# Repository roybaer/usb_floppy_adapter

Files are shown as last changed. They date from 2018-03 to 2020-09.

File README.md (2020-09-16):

# USB to Floppy-Disk Drive Adapter

This project provides the CAD files for an STM32-based floppy-disk controller that can be attached to the back of an ordinary 3.5 inch floppy-disk drive and connected to a USB host via micro USB port.

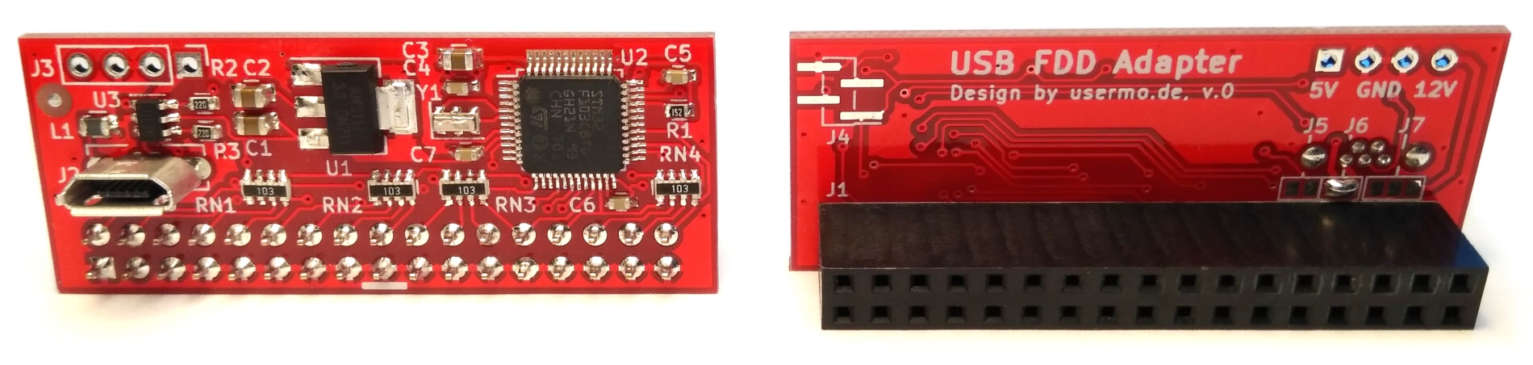
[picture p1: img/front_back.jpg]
USB FDD Adapter front and back


## Hardware

The core of this adapter is the popular STM32F103C8T6 microcontroller by STMicroelectronics.
Please consult the [PDF schematic](schematic.pdf) for details.

### Configuration

The adapter can be used in several different hardware configurations that can be selected via solder bridges.

The following drive types are supported:

- PC drives
- IBM PS/2 drives
- drives with shugart interface

Drives that only use the 5V line and consume less than approx. 480mA can be powered via USB, other drives have to be powered externally.

J5    | J6    | J7       | Use case
------|-------|----------|---------
▒▒░▒▒ | ▒▒░▒▒ | ▒▒░▒▒░▒▒ | PC drive, externally powered
▓▓▓▓▓ | ▒▒░▒▒ | ▒▒░▒▒░▒▒ | IBM PS/2 drive without 12V line
▒▒░▒▒ | ▓▓▓▓▓ | ▒▒░▒▒░▒▒ | PC drive, USB-powered
▒▒░▒▒ | ▒▒░▒▒ | ▓▓▓▓▓░▒▒ | pin 4 and 6 shorted, for shugart drives that do not use pin 4
▒▒░▒▒ | ▒▒░▒▒ | ▒▒░▓▓▓▓▓ | 12V on pin 4, for PS/2 drive

The power connector J3 can be used as either input or output.

Configurations other than the USB-powered PC drive (see [picture](img/pc_drive.jpg)) are untested.

## Firmware

As of August 2020, there is no working firmware for this adapter, yet.

The objective is to adapt the firmware provided by the [Greaseweazle project](https://github.com/keirf/Greaseweazle).
It does already provide support for the same microcontroller, albeit for a much bulkier adapter with a different pinout.

### Programming via Serial Wire Debug Interface

The adapter provides solder pads for an SWD programming device. They are labeled J4 on the PCB.

Pin on J4 | Function
----------|---------
1 | 3.3V
2 | SWDIO
3 | SWCLK
4 | GND

## Software

Please refer to the Greaseweazle documentation for PC-side software that will be used with this adapter.

## License

The following license applies to the files in this repository:

This work is licensed under the Creative Commons Attribution-ShareAlike 4.0 International License. To view a copy of this license, visit http://creativecommons.org/licenses/by-sa/4.0/ or send a letter to Creative Commons, PO Box 1866, Mountain View, CA 94042, USA.

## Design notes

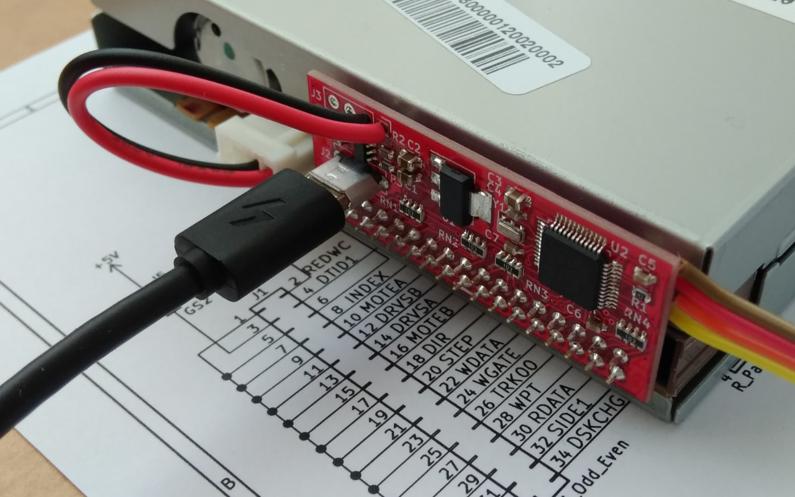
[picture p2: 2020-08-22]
img/pc_drive.jpg

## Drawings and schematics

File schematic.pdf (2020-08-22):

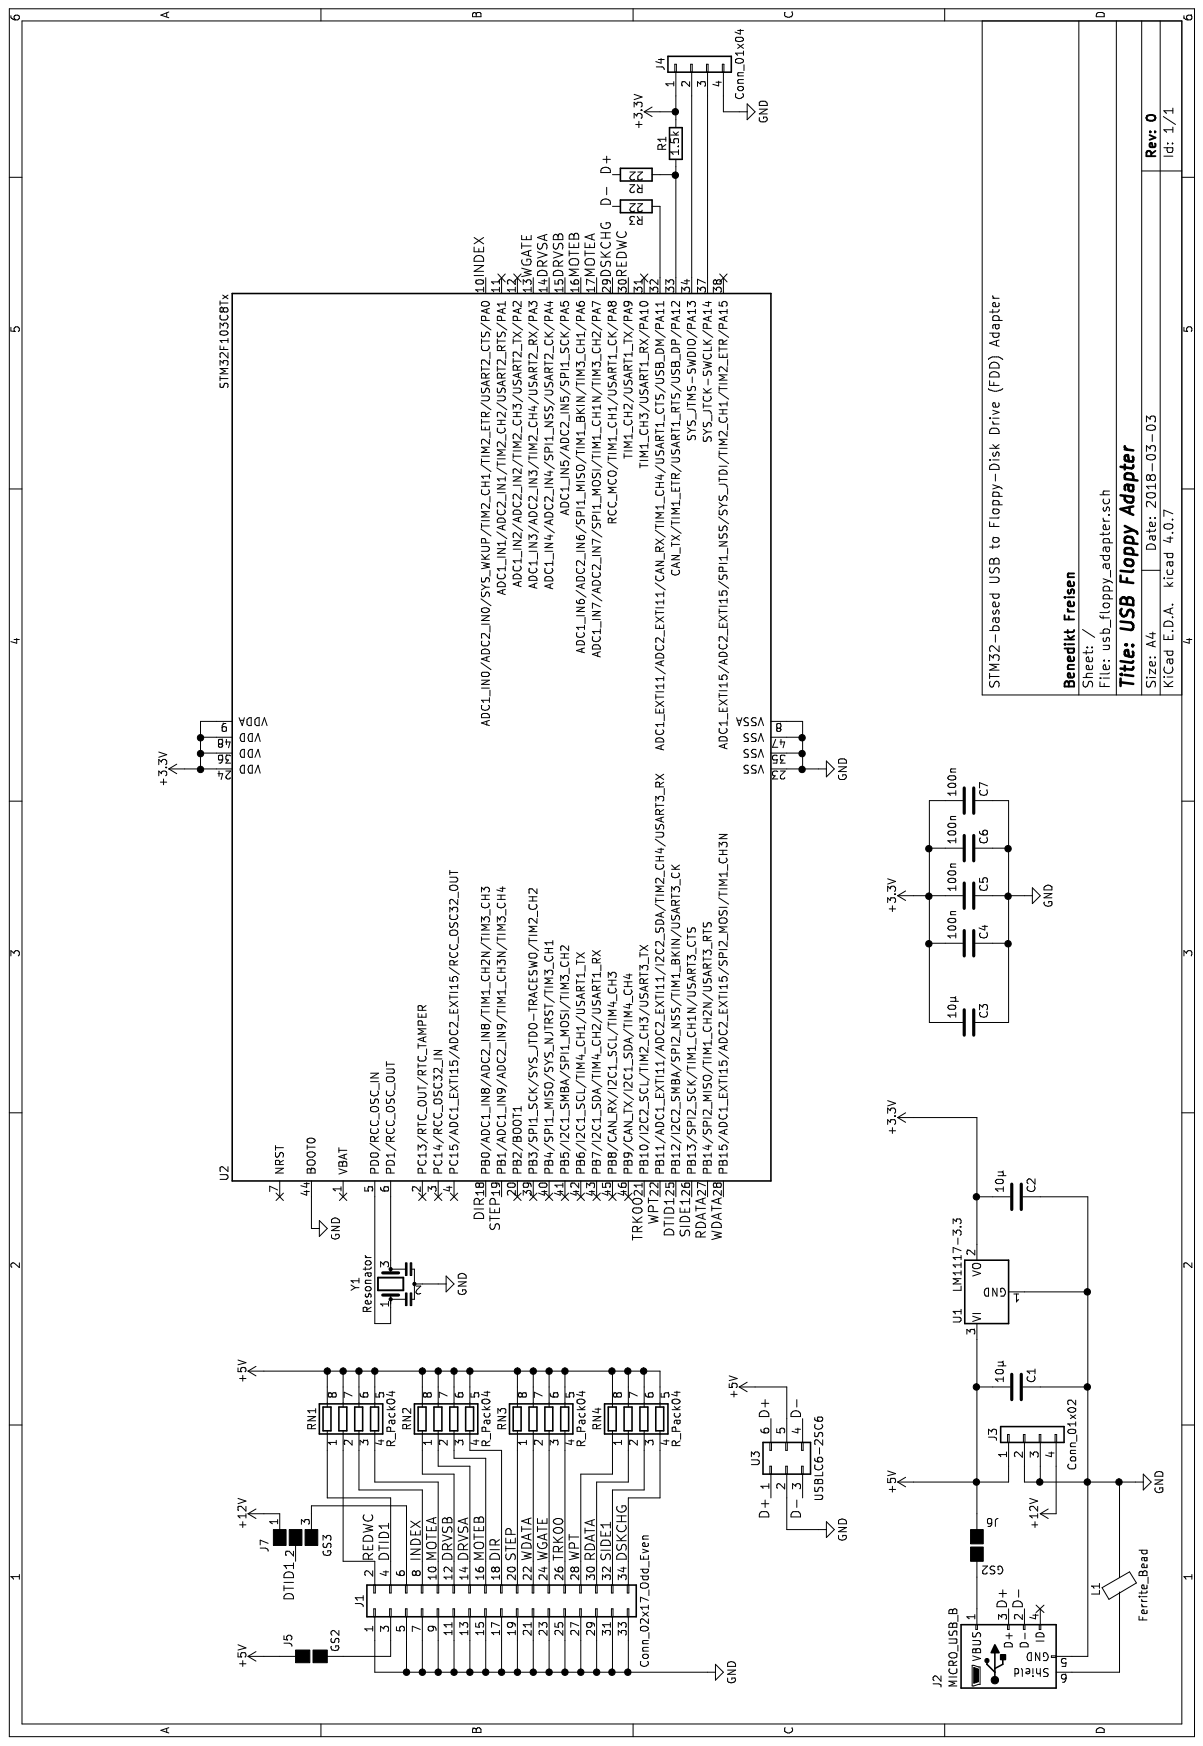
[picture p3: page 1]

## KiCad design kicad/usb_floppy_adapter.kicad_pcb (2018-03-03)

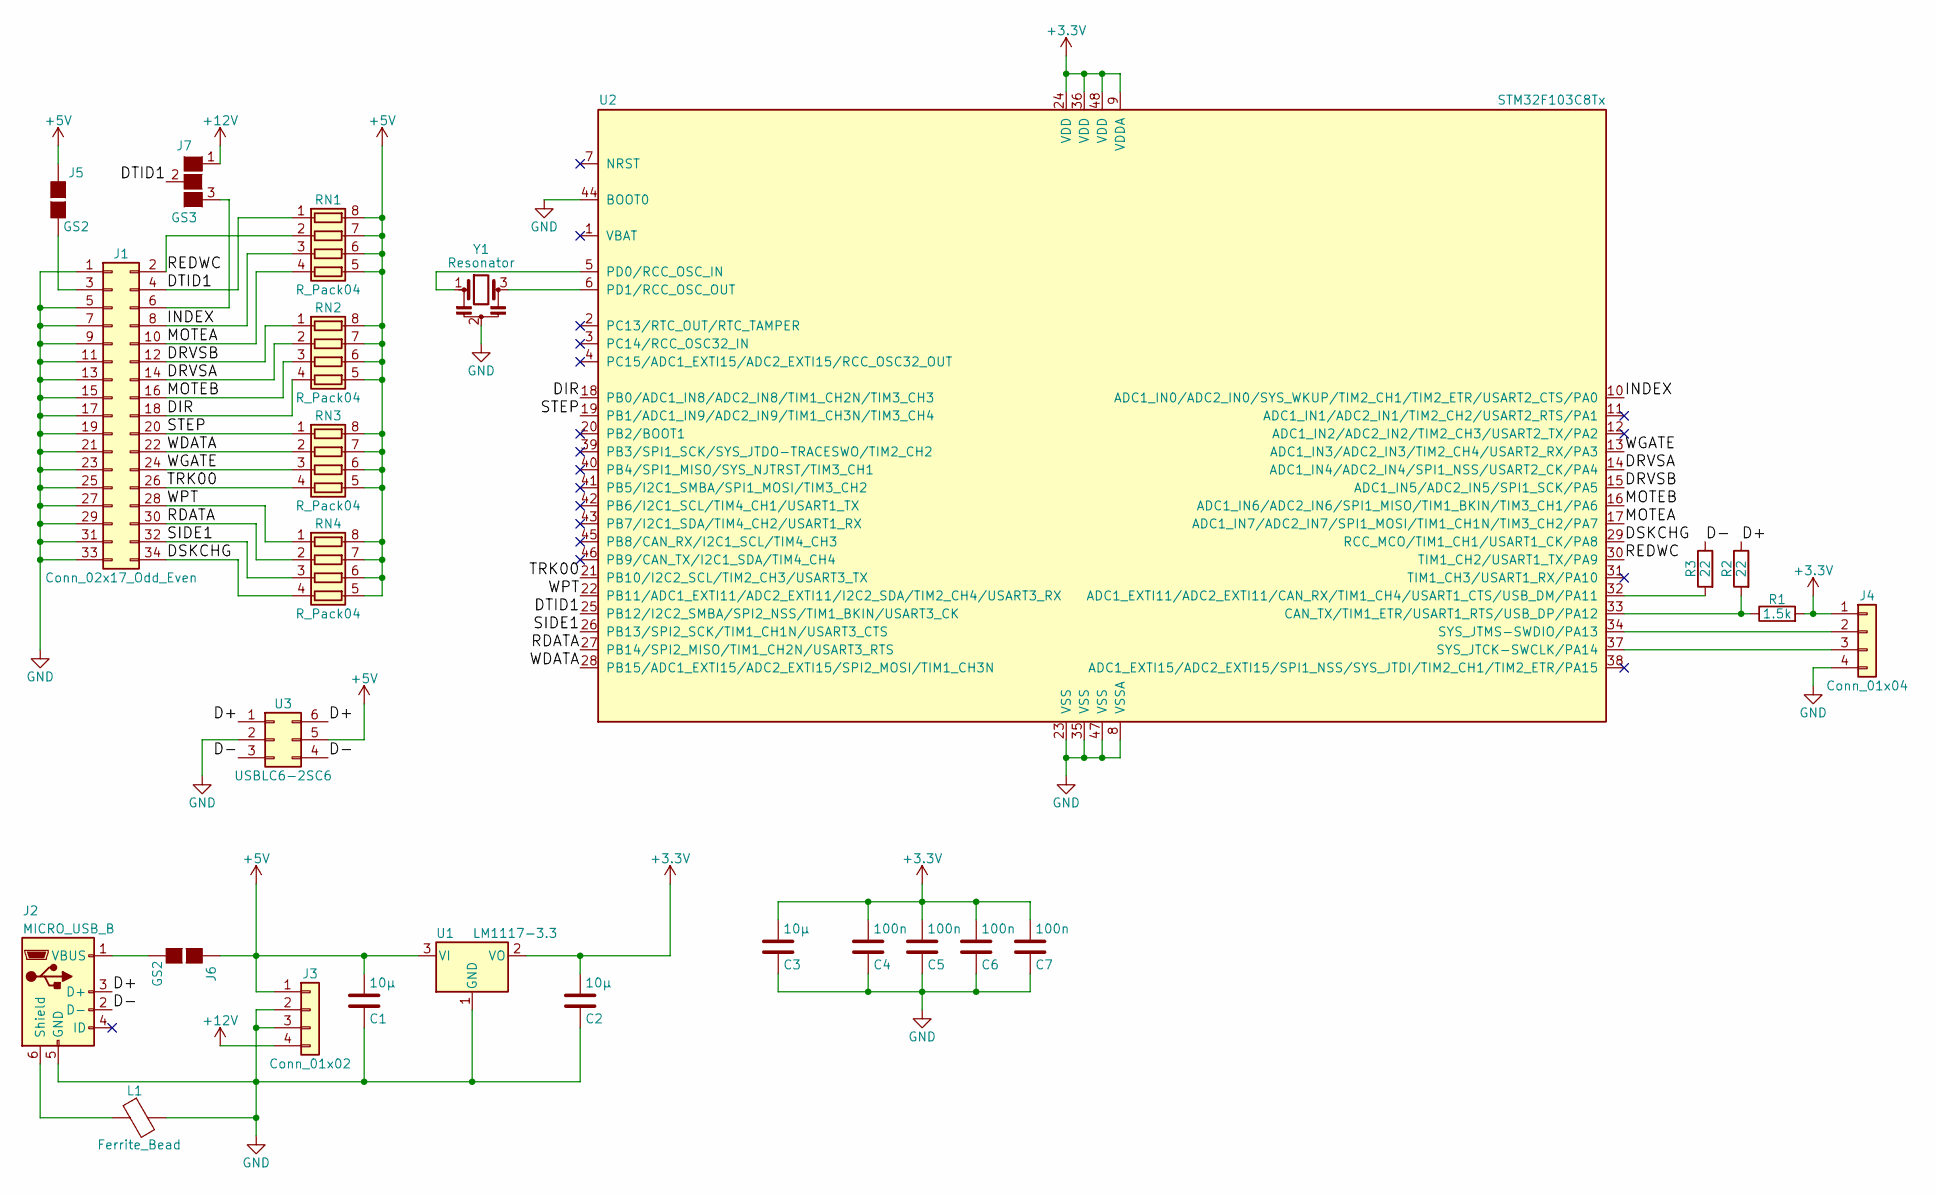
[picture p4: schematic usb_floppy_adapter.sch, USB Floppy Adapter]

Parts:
C1, C2, C3: 10µ; C_0805
C4, C5, C6, C7: 100n; C_0603
J1: Conn_02x17_Odd_Even; Socket_Strip_Straight_2x17_Pitch2.54mm
J2: MICRO_USB_B; USB_Micro-B_Vertical_Molex-105133-0001
J3: Conn_01x02; Pin_Header_Straight_1x04_Pitch2.54mm
J4: Conn_01x04; Pin_Header_Straight_1x04_Pitch1.27mm_SMD_Pin1Left
J5, J6: GS2
J7: GS3
L1: Ferrite_Bead; L_0805
R1: 1.5k; R_0603
R2, R3: 22; R_0603
RN1, RN2, RN3, RN4: R_Pack04; R_Array_Convex_4x0603
U1: LM1117-3.3; SOT-223-3Lead_TabPin2
U2: STM32F103C8Tx; LQFP-48_7x7mm_Pitch0.5mm
U3: USBLC6-2SC6; SOT-23-6
Y1: Resonator; Resonator_SMD_muRata_SFECV-3pin_6.9x2.9mm

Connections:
+3V3: C2.2, C3.2, C4.2, C5.2, C6.2, C7.2, J4.1, R1.2, U1.2 (VO), U2.9 (VDDA), U2.24 (VDD), U2.36 (VDD), U2.48 (VDD)
+5V: C1.2, J3.1, J5.1 (G1), J6.1 (G1), RN1.5 (R4.2), RN1.6 (R3.2), RN1.7 (R2.2), RN1.8 (R1.2), RN2.5 (R4.2), RN2.6 (R3.2), RN2.7 (R2.2), RN2.8 (R1.2), RN3.5 (R4.2), RN3.6 (R3.2), RN3.7 (R2.2), RN3.8 (R1.2), RN4.5 (R4.2), RN4.6 (R3.2), RN4.7 (R2.2), RN4.8 (R1.2), U1.3 (VI), U3.5
+12V: J3.4, J7.1 (G1)
/D+: J2.3 (D+), R2.1, U3.1, U3.6
/D-: J2.2 (D-), R3.1, U3.3, U3.4
/DIR: J1.18, RN2.4 (R4.1), U2.18 (PB0/ADC1_IN8/ADC2_IN8/TIM1_CH2N/TIM3_CH3)
/DRVSA: J1.14, RN2.2 (R2.1), U2.14 (ADC1_IN4/ADC2_IN4/SPI1_NSS/USART2_CK/PA4)
/DRVSB: J1.12, RN2.1 (R1.1), U2.15 (ADC1_IN5/ADC2_IN5/SPI1_SCK/PA5)
/DSKCHG: J1.34, RN4.4 (R4.1), U2.29 (RCC_MCO/TIM1_CH1/USART1_CK/PA8)
/DTID1: J1.4, J7.2 (G2), RN1.1 (R1.1), U2.25 (PB12/I2C2_SMBA/SPI2_NSS/TIM1_BKIN/USART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)
/INDEX: J1.8, RN1.3 (R3.1), U2.10 (ADC1_IN0/ADC2_IN0/SYS_WKUP/TIM2_CH1/TIM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)
/MOTEA: J1.10, RN1.4 (R4.1), U2.17 (ADC1_IN7/ADC2_IN7/SPI1_MOSI/TIM1_CH1N/T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)
/MOTEB: J1.16, RN2.3 (R3.1), U2.16 (ADC1_IN6/ADC2_IN6/SPI1_MISO/TIM1_BKIN/T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)
/RDATA: J1.30, RN4.2 (R2.1), U2.27 (PB14/SPI2_MISO/TIM1_CH2N/USART3_RTS)
/REDWC: J1.2, RN1.2 (R2.1), U2.30 (TIM1_CH2/USART1_TX/PA9)
/SIDE1: J1.32, RN4.3 (R3.1), U2.26 (PB13/SPI2_SCK/TIM1_CH1N/USART3_CTS)
/STEP: J1.20, RN3.1 (R1.1), U2.19 (PB1/ADC1_IN9/ADC2_IN9/TIM1_CH3N/TIM3_CH4)
/TRK00: J1.26, RN3.4 (R4.1), U2.21 (PB10/I2C2_SCL/TIM2_CH3/USART3_TX)
/WDATA: J1.22, RN3.2 (R2.1), U2.28 (PB15/ADC1_EXTI15/ADC2_EXTI15/SPI2_MOSI/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)
/WGATE: J1.24, RN3.3 (R3.1), U2.13 (ADC1_IN3/ADC2_IN3/TIM2_CH4/USART2_RX/PA3)
/WPT: J1.28, RN4.1 (R1.1), U2.22 (PB11/ADC1_EXTI11/ADC2_EXTI11/I2C2_SDA/T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)
GND: C1.1, C2.1, C3.1, C4.1, C5.1, C6.1, C7.1, J1.1, J1.5, J1.7, J1.9, J1.11, J1.13, J1.15, J1.17, J1.19, J1.21, J1.23, J1.25, J1.27, J1.29, J1.31, J1.33, J2.5 (GND), J3.2, J3.3, J4.4, L1.2, U1.1 (GND), U2.8 (VSSA), U2.23 (VSS), U2.35 (VSS), U2.44 (BOOT0), U2.47 (VSS), U3.2, Y1.2
unnamed: J1.3, J5.2 (G2)
unnamed: J1.6, J7.3 (G3)
unnamed: J2.1 (VBUS), J6.2 (G2)
unnamed: J2.6 (Shield), L1.1
unnamed: J4.2, U2.34 (SYS_JTMS-SWDIO/PA13)
unnamed: J4.3, U2.37 (SYS_JTCK-SWCLK/PA14)
unnamed: R1.1, R2.2, U2.33 (CAN_TX/TIM1_ETR/USART1_RTS/USB_DP/PA12)
unnamed: R3.2, U2.32 (ADC1_EXTI11/ADC2_EXTI11/CAN_RX/TIM1_CH4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)
unnamed: U2.5 (PD0/RCC_OSC_IN), Y1.1
unnamed: U2.6 (PD1/RCC_OSC_OUT), Y1.3

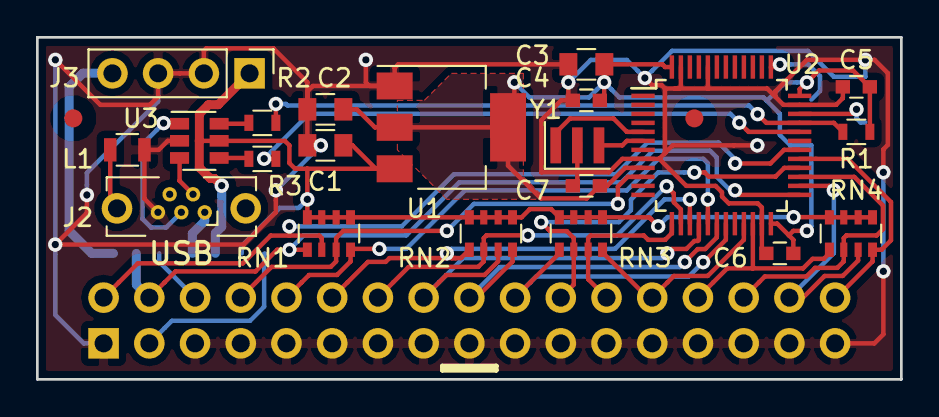
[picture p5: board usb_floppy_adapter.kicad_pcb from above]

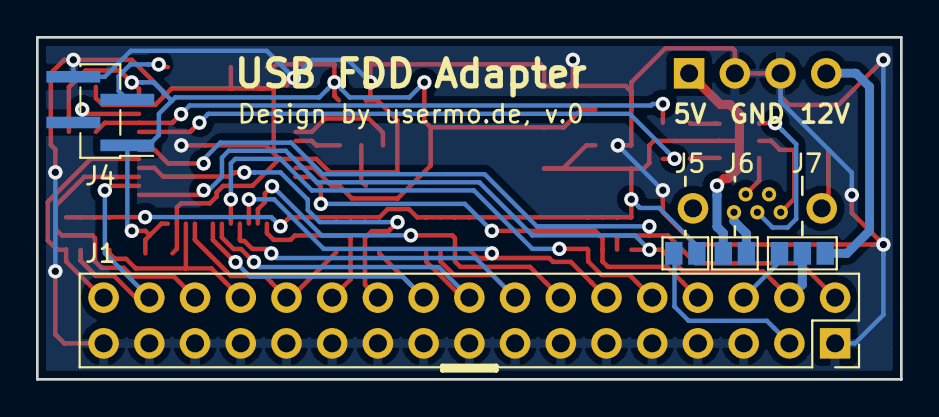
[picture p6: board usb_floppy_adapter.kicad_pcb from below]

Board: 2 copper layers, 48.0 x 19.0 mm, 26 parts (5 on the bottom side), 32 nets.

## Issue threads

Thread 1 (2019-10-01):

no firmware.

youxiaojie, 2019-10-01:
no firmware.

roybaer, 2019-10-01:
The repository does not contain any firmware, because there is no firmware for the device, yet.
The only thing that exists is an stm32duino sketch that reads a number from a serial connection and moves the drive head to that position.

roybaer, 2019-11-04:
It should be possible to adapt the Greaseweazle software.  See https://github.com/keirf/Greaseweazle/issues/4.

roybaer, 2025-02-21:
Yes, for the time being, this has been abandoned. If and when I return to it, I will probably redesign the PCB layout to adopt the exact pinout used by Greaseweazle for "blue pill" adapter boards. There were a few issues with my choice of µC pins and the pull-up resistors appear to be largely unnecessary, too, because the FDD bus uses TTL compatible levels, anyway.
I did not pursue this any further after finding out that my USB FDD actually supports 720 KiB DD disks once they have been formatted elsewhere, and that was my primary use case.

Bottom line: You can already use a "blue pill" board with Greazeweazle if you don't care about a pretty circuit board.
At this point, I'd rather redesign the board to use unmodified firmware and not do it the other way around.

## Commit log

2018-02-04 add termination resistors
    [usb_floppy_adapter.kicad_pcb, usb_floppy_adapter.sch]
2018-02-08 silk screen
    [usb_floppy_adapter.kicad_pcb]
2018-02-08 set board thickness to 1.2mm
    [usb_floppy_adapter.kicad_pcb]
2018-03-03 Preparations for first prototype run
    - Tie BOOT0 to GND to ensure proper boot-up
    - Mark all unused MCU pins in the schematic as N/C
    - Double the width of the most important 5V and 12V traces
    - Move some traces further away from pads
    - Optimize parameters of Copper Fills
    - Add meta data and revision number (revision 0)
    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
    [usb_floppy_adapter.kicad_pcb, usb_floppy_adapter.sch]
